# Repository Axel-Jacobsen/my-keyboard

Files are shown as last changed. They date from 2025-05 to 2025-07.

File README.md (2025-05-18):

# Plan

split keyboard, fun to make and fun to have

TODOs
=====
[ ] swap to low profile keys
[ ] expose scl, sda
[ ] tighten up PCB

microcontroller
===============
- connection type
  - wired
    - pros: no battery, simpler, would be fun to program bluetooth controller
    - cons: annoying while using
  - bluetooth:
    - pros: clean to use
    - cons: battery is annoying
  - *decision*
    - wired to start[0] - bluetooth will make the project more complicated than necessary
- possible options
  - ATmega32U4 (widely used, looks small)
    - as raw IC mounted on the PCB (more complicated, so don't do) or as a "hat" on a breakout board
      - https://www.microchip.com/en-us/product/atmega32u4
      - https://learn.sparkfun.com/tutorials/pro-micro--fio-v3-hookup-guide/hardware-overview-pro-micro
  - STM32F103 (powerful, bigger)
- microcontroller -> pcb - how to connect?
  - solder directly to pcb
    - pros: fuckin sick, may be cheaper? maybe not
    - cons: much more difficult to manufacture
  - get breakout and solder the pins
    - pros: much easier to deal with
    - cons: less fkn tight
  - *decision*
    - do breakout for v1
- *variables to minimize*
  - size
  - power consumption
  - key-press latency

eece / computer
===============
- need to be able to detect any combination of keys together simultaneously
- sw
  - rust ;)
    - avr rust book: https://book.avr-rust.org/
    - https://docs.rs/avrd/latest/avrd/atmega16u4/index.html
  - implements USB HID 1.11 + reading gpio inputs
- elec
  - nice looking pcb
  - reading keys
    - keyboard matrix
      - pros: simple
    - shift registers (74HC165) to multiplex data in
      - pros: sort of more interesting
    - *decision*
      - keyboard matrix. simpler is better.
  - is there a little led grid that I could have sitting somewhere flashing when keys are pressed?

keys + key caps
===============

- A 61 key keyboard is common - a "60%" - but what do I need?
  - want 60 keys minimum
    - 26 for the letters of the alphabet
    - 10 for decimal digits
    - 1 for +
    - 1 for -
    - 1 for spacebar
    - 3 for control, option, command
    - 1 for escape (in caps lock position)
    - 1 for tilde
    - 1 for tab
    - 1 for shift
    - 1 for ;
    - 1 for '
    - 1 for delete
    - 2 for <>
    - 2 for []
    - 1 for ?
    - 1 for \
    - 4 for arrow keys
    - 1 for special key 1
  - with another 5,
    - 1 for split spacebar
    - 1 for another special key
    - ??? three fun extra keys
- key type
  - mechanical keys
    - pros: maybe sounds good
    - cons: misclick frequently, more tiring to type, slow
  - flat keys
    - pros: easier to press, faster to type
    - cons: less cool?
  - *decision*
    - search for flat keys and mechanical keys, should be able to make keybaords with either in the same way

[1]: https://www.digikey.com/en/products/detail/gct/USB4085-GF-A/9859662

[0]: [usb c breakout](https://tinyurl.com/269dkzz5) or [this full breakout](https://www.adafruit.com/product/4396#description)

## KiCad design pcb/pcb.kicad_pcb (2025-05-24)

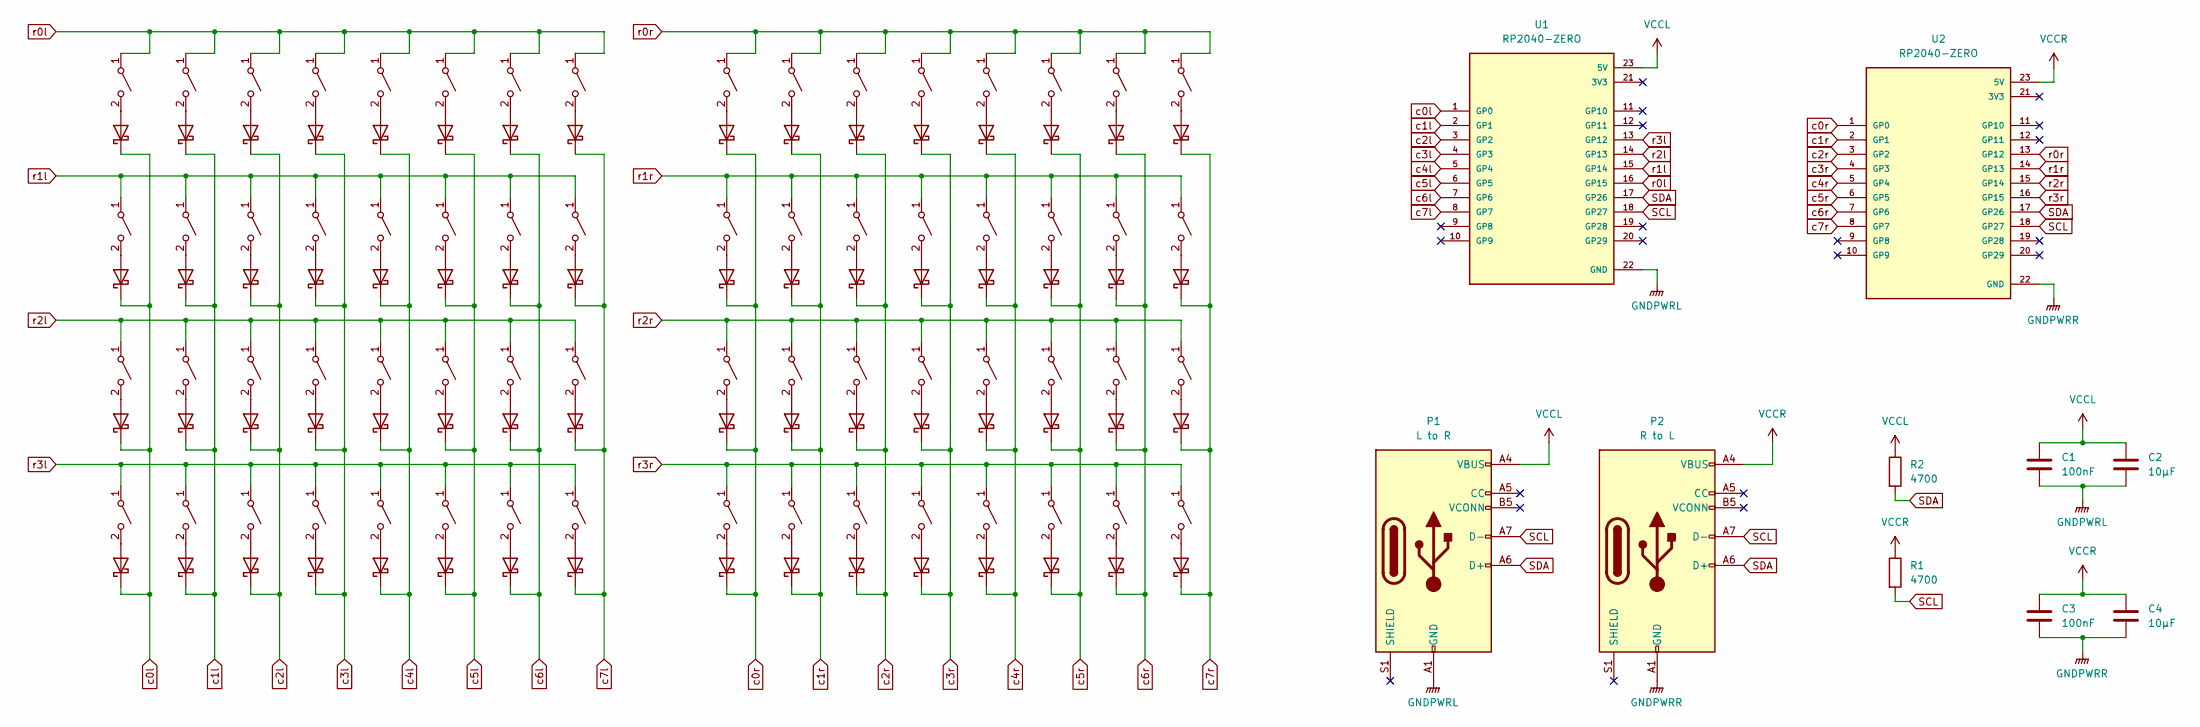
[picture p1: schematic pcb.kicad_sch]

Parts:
C1, C3: 100nF; C_1206_3216Metric_Pad1.33x1.80mm_HandSolder
C2, C4: 10µF; C_1206_3216Metric_Pad1.33x1.80mm_HandSolder
D1, D2, D3, D4, D5, D6, D7, D8, D9, D10, D11, D12, D13, D14, D15, D16, D17, D18, D19, D20, D21, D22, D23, D24, D25, D26, D27, D28, D29, D30, D31, D32, D33, D34, D35, D36, D37, D38, D39, D40, D41, D42, D43, D44, D45, D46, D47, D48, D49, D50, D51, D52, D53, D54, D55, D56, D57, D58, D59, D60, D61, D62, D63, D64: 1N5817; D_DO-41_SOD81_P10.16mm_Horizontal
P1: L to R; USB_C_Receptacle_GCT_USB4085
P2: R to L; USB_C_Receptacle_GCT_USB4085
R1, R2: 4700; R_1206_3216Metric_Pad1.30x1.75mm_HandSolder
SW1, SW2, SW3, SW4, SW5, SW6, SW7, SW8, SW9, SW10, SW11, SW12, SW13, SW14, SW15, SW16, SW17, SW18, SW19, SW20, SW21, SW22, SW23, SW24, SW25, SW26, SW27, SW28, SW29, SW30, SW31, SW32, SW33, SW34, SW35, SW36, SW37, SW38, SW39, SW40, SW41, SW42, SW43, SW44, SW45, SW46, SW47, SW48, SW49, SW50, SW51, SW52, SW53, SW54, SW55, SW56, SW57, SW58, SW59, SW60, SW61, SW62, SW63, SW64: SW_SPST; SW_Kailh_Choc_V2_THT
U1, U2: RP2040-ZERO; MODULE_RP2040-ZERO; PARTREV NA

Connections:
GNDPWRL: C1.2, C2.2, P1.A1 (GND), P1.A12 (GND), P1.B1 (GND), P1.B12 (GND), U1.22 (GND)
GNDPWRR: C3.2, C4.2, P2.A1 (GND), P2.A12 (GND), P2.B1 (GND), P2.B12 (GND), U2.22 (GND)
unnamed: D1.2 (A), SW1.2 (B)
unnamed: D2.2 (A), SW2.2 (B)
unnamed: D3.2 (A), SW3.2 (B)
unnamed: D4.2 (A), SW4.2 (B)
unnamed: D5.2 (A), SW5.2 (B)
unnamed: D6.2 (A), SW6.2 (B)
unnamed: D7.2 (A), SW7.2 (B)
unnamed: D8.2 (A), SW8.2 (B)
unnamed: D9.2 (A), SW9.2 (B)
unnamed: D10.2 (A), SW10.2 (B)
unnamed: D11.2 (A), SW11.2 (B)
unnamed: D12.2 (A), SW12.2 (B)
unnamed: D13.2 (A), SW13.2 (B)
unnamed: D14.2 (A), SW14.2 (B)
unnamed: D15.2 (A), SW15.2 (B)
unnamed: D16.2 (A), SW16.2 (B)
unnamed: D17.2 (A), SW17.2 (B)
unnamed: D18.2 (A), SW18.2 (B)
unnamed: D19.2 (A), SW19.2 (B)
unnamed: D20.2 (A), SW20.2 (B)
unnamed: D21.2 (A), SW21.2 (B)
unnamed: D22.2 (A), SW22.2 (B)
unnamed: D23.2 (A), SW23.2 (B)
unnamed: D24.2 (A), SW24.2 (B)
unnamed: D25.2 (A), SW25.2 (B)
unnamed: D26.2 (A), SW26.2 (B)
unnamed: D27.2 (A), SW27.2 (B)
unnamed: D28.2 (A), SW28.2 (B)
unnamed: D29.2 (A), SW29.2 (B)
unnamed: D30.2 (A), SW30.2 (B)
unnamed: D31.2 (A), SW31.2 (B)
unnamed: D32.2 (A), SW32.2 (B)
unnamed: D33.2 (A), SW33.2 (B)
unnamed: D34.2 (A), SW34.2 (B)
unnamed: D35.2 (A), SW35.2 (B)
unnamed: D36.2 (A), SW36.2 (B)
unnamed: D37.2 (A), SW37.2 (B)
unnamed: D38.2 (A), SW38.2 (B)
unnamed: D39.2 (A), SW39.2 (B)
unnamed: D40.2 (A), SW40.2 (B)
unnamed: D41.2 (A), SW41.2 (B)
unnamed: D42.2 (A), SW42.2 (B)
unnamed: D43.2 (A), SW43.2 (B)
unnamed: D44.2 (A), SW44.2 (B)
unnamed: D45.2 (A), SW45.2 (B)
unnamed: D46.2 (A), SW46.2 (B)
unnamed: D47.2 (A), SW47.2 (B)
unnamed: D48.2 (A), SW48.2 (B)
unnamed: D49.2 (A), SW49.2 (B)
unnamed: D50.2 (A), SW50.2 (B)
unnamed: D51.2 (A), SW51.2 (B)
unnamed: D52.2 (A), SW52.2 (B)
unnamed: D53.2 (A), SW53.2 (B)
unnamed: D54.2 (A), SW54.2 (B)
unnamed: D55.2 (A), SW55.2 (B)
unnamed: D56.2 (A), SW56.2 (B)
unnamed: D57.2 (A), SW57.2 (B)
unnamed: D58.2 (A), SW58.2 (B)
unnamed: D59.2 (A), SW59.2 (B)
unnamed: D60.2 (A), SW60.2 (B)
unnamed: D61.2 (A), SW61.2 (B)
unnamed: D62.2 (A), SW62.2 (B)
unnamed: D63.2 (A), SW63.2 (B)
unnamed: D64.2 (A), SW64.2 (B)
SCL: P1.A7 (D-), P2.A7 (D-), R1.2, U1.18 (GP27), U2.18 (GP27)
SDA: P1.A6 (D+), P2.A6 (D+), R2.2, U1.17 (GP26), U2.17 (GP26)
VCCL: C1.1, C2.1, P1.A4 (VBUS), P1.A9 (VBUS), P1.B4 (VBUS), P1.B9 (VBUS), R2.1, U1.23 (5V)
VCCR: C3.1, C4.1, P2.A4 (VBUS), P2.A9 (VBUS), P2.B4 (VBUS), P2.B9 (VBUS), R1.1, U2.23 (5V)
c0l: D1.1 (K), D2.1 (K), D3.1 (K), D4.1 (K), U1.1 (GP0)
c0r: D6.1 (K), D12.1 (K), D18.1 (K), D24.1 (K), U2.1 (GP0)
c1l: D7.1 (K), D8.1 (K), D9.1 (K), D10.1 (K), U1.2 (GP1)
c1r: D30.1 (K), D36.1 (K), D37.1 (K), D38.1 (K), U2.2 (GP1)
c2l: D13.1 (K), D14.1 (K), D15.1 (K), D16.1 (K), U1.3 (GP2)
c2r: D39.1 (K), D40.1 (K), D41.1 (K), D42.1 (K), U2.3 (GP2)
c3l: D19.1 (K), D20.1 (K), D21.1 (K), D22.1 (K), U1.4 (GP3)
c3r: D43.1 (K), D44.1 (K), D45.1 (K), D46.1 (K), U2.4 (GP3)
c4l: D25.1 (K), D26.1 (K), D27.1 (K), D28.1 (K), U1.5 (GP4)
c4r: D47.1 (K), D48.1 (K), D49.1 (K), D50.1 (K), U2.5 (GP4)
c5l: D31.1 (K), D32.1 (K), D33.1 (K), D34.1 (K), U1.6 (GP5)
c5r: D51.1 (K), D52.1 (K), D53.1 (K), D54.1 (K), U2.6 (GP5)
c6l: D5.1 (K), D11.1 (K), D17.1 (K), D23.1 (K), U1.7 (GP6)
c6r: D55.1 (K), D56.1 (K), D57.1 (K), D58.1 (K), U2.7 (GP6)
c7l: D29.1 (K), D35.1 (K), D61.1 (K), D62.1 (K), U1.8 (GP7)
c7r: D59.1 (K), D60.1 (K), D63.1 (K), D64.1 (K), U2.8 (GP7)
r0l: SW1.1 (A), SW5.1 (A), SW7.1 (A), SW13.1 (A), SW19.1 (A), SW25.1 (A), SW29.1 (A), SW31.1 (A), U1.16 (GP15)
r0r: SW6.1 (A), SW30.1 (A), SW39.1 (A), SW43.1 (A), SW47.1 (A), SW51.1 (A), SW55.1 (A), SW59.1 (A), U2.13 (GP12)
r1l: SW2.1 (A), SW8.1 (A), SW11.1 (A), SW14.1 (A), SW20.1 (A), SW26.1 (A), SW32.1 (A), SW35.1 (A), U1.15 (GP14)
r1r: SW12.1 (A), SW36.1 (A), SW40.1 (A), SW44.1 (A), SW48.1 (A), SW52.1 (A), SW56.1 (A), SW60.1 (A), U2.14 (GP13)
r2l: SW3.1 (A), SW9.1 (A), SW15.1 (A), SW17.1 (A), SW21.1 (A), SW27.1 (A), SW33.1 (A), SW61.1 (A), U1.14 (GP13)
r2r: SW18.1 (A), SW37.1 (A), SW41.1 (A), SW45.1 (A), SW49.1 (A), SW53.1 (A), SW57.1 (A), SW63.1 (A), U2.15 (GP14)
r3l: SW4.1 (A), SW10.1 (A), SW16.1 (A), SW22.1 (A), SW23.1 (A), SW28.1 (A), SW34.1 (A), SW62.1 (A), U1.13 (GP12)
r3r: SW24.1 (A), SW38.1 (A), SW42.1 (A), SW46.1 (A), SW50.1 (A), SW54.1 (A), SW58.1 (A), SW64.1 (A), U2.16 (GP15)

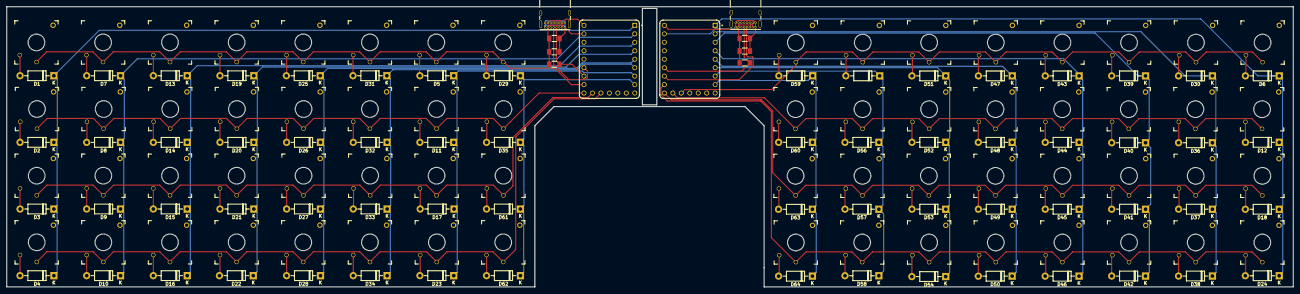
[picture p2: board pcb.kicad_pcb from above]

Board: 2 copper layers, 386.1 x 84.1 mm, 138 parts (0 on the bottom side), 94 nets.

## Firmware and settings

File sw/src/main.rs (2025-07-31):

#![no_std]
#![no_main]

mod matrix;
mod types;

use crate::types::{Key, Side};

use core::sync::atomic::{AtomicBool, Ordering};

use embassy_executor::Spawner;
use embassy_futures::join::join5;
use embassy_rp::bind_interrupts;
use embassy_rp::gpio::{Input, Level, Output, Pull};
use embassy_rp::peripherals::USB;
use embassy_rp::usb::{Driver, InterruptHandler};
use embassy_sync::blocking_mutex::raw::ThreadModeRawMutex;
use embassy_sync::channel::Channel;
use embassy_usb::class::cdc_acm::{CdcAcmClass, State as CdcState};
use embassy_usb::class::hid::{HidReaderWriter, ReportId, RequestHandler, State};
use embassy_usb::control::OutResponse;
use embassy_usb::{Builder, Config, Handler};
use static_cell::StaticCell;
use usbd_hid::descriptor::{KeyboardReport, SerializedDescriptor};
use {defmt_rtt as _, panic_probe as _};

bind_interrupts!(struct Irqs {
    USBCTRL_IRQ => InterruptHandler<USB>;
});

#[defmt::panic_handler]
fn panic() -> ! {
    defmt::panic!()
}

#[embassy_executor::main]
async fn main(_spawner: Spawner) {
    let p = embassy_rp::init(Default::default());
    let driver = Driver::new(p.USB, Irqs);

    let config = {
        let mut config = Config::new(0xc0de, 0xcafe);
        config.manufacturer = Some("Embassy");
        config.product = Some("HID keyboard example");
        config.serial_number = Some("12345678");
        config.max_power = 100;
        config.max_packet_size_0 = 64;
        config
    };

    let mut builder = {
        static CONFIG_DESCRIPTOR: StaticCell<[u8; 256]> = StaticCell::new();
        static BOS_DESCRIPTOR: StaticCell<[u8; 256]> = StaticCell::new();
        static MSOS_DESCRIPTOR: StaticCell<[u8; 256]> = StaticCell::new();
        static CONTROL_BUF: StaticCell<[u8; 64]> = StaticCell::new();

        let mut builder = Builder::new(
            driver,
            config,
            CONFIG_DESCRIPTOR.init([0; 256]),
            BOS_DESCRIPTOR.init([0; 256]),
            MSOS_DESCRIPTOR.init([0; 256]),
            CONTROL_BUF.init([0; 64]),
        );

        static DEVICE_HANDLER: StaticCell<StubDeviceHandler> = StaticCell::new();
        builder.handler(DEVICE_HANDLER.init(StubDeviceHandler::new()));
        builder
    };

    let config = embassy_usb::class::hid::Config {
        report_descriptor: KeyboardReport::desc(),
        request_handler: None,
        poll_ms: 10,
        max_packet_size: 64,
    };

    let hid = {
        static STATE: StaticCell<State> = StaticCell::new();
        let state = STATE.init(State::new());
        HidReaderWriter::<_, 1, 8>::new(&mut builder, state, config)
    };

    static LEFT_ROWS: StaticCell<[Output; 4]> = StaticCell::new();
    let left_rows = LEFT_ROWS.init([
        Output::new(p.PIN_15, Level::Low),
        Output::new(p.PIN_14, Level::Low),
        Output::new(p.PIN_13, Level::Low),
        Output::new(p.PIN_12, Level::Low),
    ]);
    static LEFT_COLS: StaticCell<[Input; 8]> = StaticCell::new();
    let left_cols = LEFT_COLS.init([
        Input::new(p.PIN_0, Pull::None),
        Input::new(p.PIN_1, Pull::None),
        Input::new(p.PIN_2, Pull::None),
        Input::new(p.PIN_3, Pull::None),
        Input::new(p.PIN_4, Pull::None),
        Input::new(p.PIN_5, Pull::None),
        Input::new(p.PIN_6, Pull::None),
        Input::new(p.PIN_7, Pull::None),
    ]);

    static REPORT_CHANNEL: StaticCell<Channel<ThreadModeRawMutex, Key, 256>> = StaticCell::new();
    let reporting_channel = REPORT_CHANNEL.init(Channel::new());

    let left_matrix_fut =
        matrix::report(left_rows, left_cols, Side::Left, reporting_channel.sender());

    let key_receiver = reporting_channel.receiver();

    let (reader, mut writer) = hid.split();
    let in_fut = async {
        const RELEASE: KeyboardReport = KeyboardReport {
            keycodes: [0; 6],
            leds: 0,
            modifier: 0,
            reserved: 0,
        };

        loop {
            log::debug!("waiting for key");
            let key = key_receiver.receive().await;
            log::debug!("received key: {:?}", key);

            // Send 'L' or 'R'
            let _ = writer
                .write(&[match key.side {
                    Side::Left => b'L',
                    Side::Right => b'R',
                }])
                .await;

            // Send ASCII digits of row_id
            let _ = writer.write(&[b'0' + (key.row_id / 10) as u8]).await;
            let _ = writer.write(&[b'0' + (key.row_id % 10) as u8]).await;

            // Send ASCII digits of col_id
            let _ = writer.write(&[b'0' + (key.col_id / 10) as u8]).await;
            let _ = writer.write(&[b'0' + (key.col_id % 10) as u8]).await;

            // Optional: newline for readability
            let _ = writer.write(&[b'\n']).await;

            let _ = writer.write_serialize(&RELEASE).await;
        }
    };

    let mut request_handler = StubRequestHandler {};
    let out_fut = async {
        reader.run(false, &mut request_handler).await;
    };

    static LOGGER_STATE: StaticCell<CdcState> = StaticCell::new();
    let logger_class = CdcAcmClass::new(&mut builder, LOGGER_STATE.init(CdcState::new()), 64);
    let log_fut = embassy_usb_logger::with_class!(1024, log::LevelFilter::Debug, logger_class);

    let mut usb = builder.build();
    let usb_fut = usb.run();

    join5(log_fut, left_matrix_fut, usb_fut, in_fut, out_fut).await;
}

struct StubRequestHandler {}

impl RequestHandler for StubRequestHandler {
    fn get_report(&mut self, _id: ReportId, _buf: &mut [u8]) -> Option<usize> {
        None
    }

    fn set_report(&mut self, _id: ReportId, _data: &[u8]) -> OutResponse {
        OutResponse::Accepted
    }

    fn set_idle_ms(&mut self, _id: Option<ReportId>, _dur: u32) {}

    fn get_idle_ms(&mut self, _id: Option<ReportId>) -> Option<u32> {
        None
    }
}

struct StubDeviceHandler {
    configured: AtomicBool,
}

impl StubDeviceHandler {
    fn new() -> Self {
        StubDeviceHandler {
            configured: AtomicBool::new(false),
        }
    }
}

impl Handler for StubDeviceHandler {
    fn enabled(&mut self, _enabled: bool) {
        self.configured.store(false, Ordering::Relaxed);
    }

    fn reset(&mut self) {
        self.configured.store(false, Ordering::Relaxed);
    }

    fn addressed(&mut self, _addr: u8) {
        self.configured.store(false, Ordering::Relaxed);
    }

    fn configured(&mut self, configured: bool) {
        self.configured.store(configured, Ordering::Relaxed);
    }
}

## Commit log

2024-10-02 save pcb
    [pcb.kicad_sch]
2025-03-10 sanity save
    [pcb.kicad_sch]
2025-03-17 upd and add switches submodule
    [pcb.kicad_sch]
2025-05-10 a lot of updates
    [pcb.kicad_pcb, pcb.kicad_sch]
2025-05-10 yooooo thankn you gpt
    [pcb.kicad_pcb]
2025-05-11 think it si there
    [pcb.kicad_pcb, pcb.kicad_sch]
2025-05-18 about tod o smth dumb
    [pcb.kicad_pcb]
2025-05-18 to low prof
    [pcb.kicad_pcb, pcb.kicad_sch]
2025-05-18 agh need to retrace some stuff will do tmmr
    [pcb.kicad_pcb]
